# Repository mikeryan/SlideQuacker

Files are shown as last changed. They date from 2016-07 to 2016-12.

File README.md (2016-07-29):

# Wrong Island Con Slide Quacker

The Wrong Island Con Slide Quacker is an electronic conference badge
that's actually useful! You can pair it with your laptop and use it as a
traditional slide clicker, as it implements the HID over GATT profile.

The firmware is an app running on [Apache
Mynewt](http://mynewt.apache.org), an open source RTOS and BLE stack.
The app is heavily based on the bleprph example application.

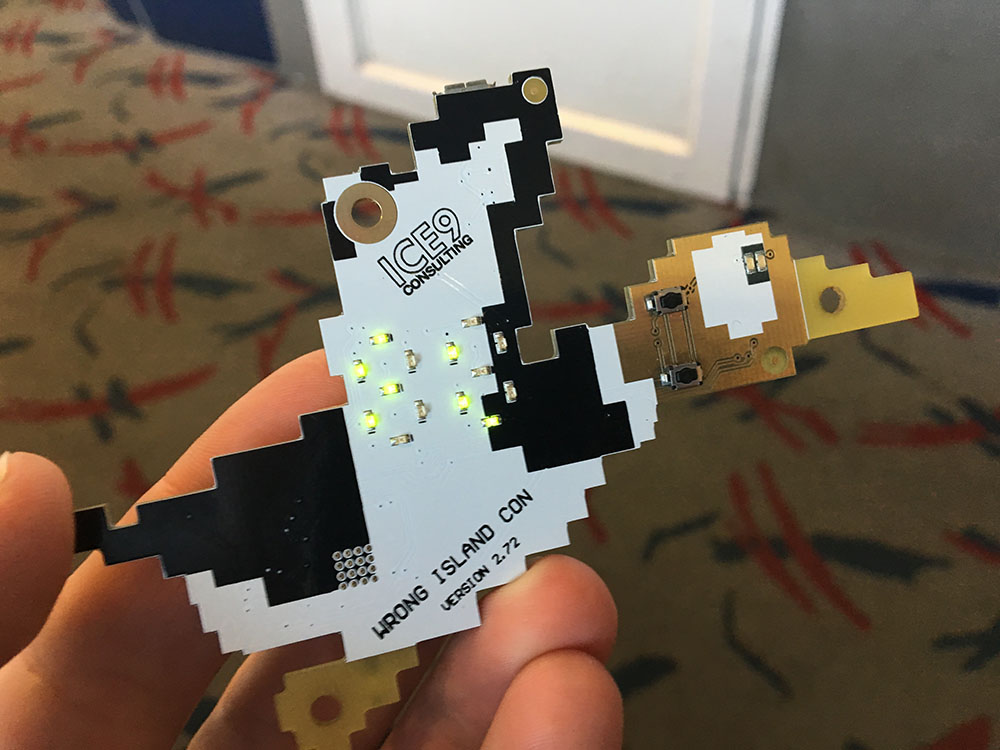
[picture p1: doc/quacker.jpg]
Slide Quacker


# Conference

This is the badge for Wrong Island Con 2.7, taking place on Catalina on
July 29th, 2016.

# Credits

- Conference: Richo Healey (http://psych0tik.net)
- Firmware: Mike Ryan of [ICE9 Consulting](http://ice9.us/)
- Hardware: nico (badge@n.routed.net)

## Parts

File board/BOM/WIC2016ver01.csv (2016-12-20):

Designator | Quantity | Description | Comment | Manufacturer | Manufacturer Part Number | Supplier 1 | Supplier Part Number 1 | Part Number
ANT1 | 1 | 2.4GHz antenna | 2.4GHz antenna | Johansen | 2450AT18A100E | Digi-Key | 712-1005-1-ND | 470-00204-00
B1 | 1 | HOLDER COIN CELL 2032 SMD | BATTERY_SOCKET_CR2032 | MPD (Memory Protection Devices) | BU2032SM-HD-G | Digi-Key | BU2032SM-HD-GDKR-ND
BAL1 | 1 |  | BAL-2450BM14E0003T
C1, C2 | 2 | CAP CER 0.1UF 100V 10% X7S 0603 | CAP_CER_0603_0.1UF_100V_10%_X7S | TDK Corporation | CGA3E3X7S2A104K080AB | Digi-Key | 445-6938-1-ND | 150-00222-00
C4, C5, C10, C11 | 4 | Capacitor, NP0, ±2% | 12pF |  |  |  |  | C0402-12p
C6, C7 | 2 | CAP CER 0.1UF 50V 10% X7R 0603 | CAP_CER_0603_0.1UF_50V_10%_X7R | TDK Corporation | CGA3E2X7R1H104K080AA | Digi-Key | 445-5666-1-ND | 150-00077-00
C8, C9 | 2 | CAP CER 2.2UF 6.3V 10% X7R 0603 | CAP_CER_0603_2.2UF_6.3V_10%_X7R | TDK Corporation | CGA3E1X7R0J225K080AC | Digi-Key | 445-6933-1-ND | 150-00101-00
C12 | 1 | CAP CER 1.5PF 100V C0G 0603 | CAP_CER_0603_1.5PF_100V_C0G | TDK Corporation | 251R14S1R0BV4T | Digi-Key | 251R14S1R0BV4T | 150-00508-00
C13 | 1 | CAP CER 0.047UF 25V 10% X7R 0603 | CAP_CER_0603_0.047UF_50V_10%_X7R | TDK Corporation | CGA3E2X7R1H473K080AA | Digi-Key | 445-5664-1-ND | 150-00147-00
C14 | 1 | CAP CER 2200PF 50V 5% NP0 0603 | CAP_CER_0603_2200PF_50V_5%_NP0 | TDK Corporation | CGA3E2C0G1H222J080AA | Digi-Key | 445-5656-1-ND | 150-00062-00
C15, C16 | 2 | CAP_CER_0603_4.7UF_6.3V_10%_X5R | CAP_CER_0603_4.7UF_6.3V_10%_X5R | TDK Corporation | CGA3E1X5R0J475K080AC | Digi-Key | 445-6934-1-ND | 150-00428-00
C17 | 1 | CAP CER 2.2UF 10V 10% X7S 0603 | CAP_CER_0603_2.2UF_10V_10%_X7S | TDK Corporation | CGA3E3X7S1A225K080AA | Digi-Key | 445-16108-1-ND | 140-00511-00
D1, D2 | 2 | LED CHIPLED BLUE 470NM 0603 SMD | LED_0603_BLUE_LB Q39G-L2N2-35-1 | OSRAM Opto Semiconductors Inc | LB Q39G-L2N2-35-1 | Digi-Key | 475-2816-1-ND | 370-00009-00
D3, D4, D5, D6, D7, D8, D9, D10, D11, D12, D13, D14, D15, D16, D18, D19 | 16 | LED GREEN CLEAR 0603 SMD | LED_0603_GREEN_LG_LTST-C190GKT | Lite-On Inc | LTST-C190GKT | Digi-Key | 160-1183-1-ND | 370-00010-00
D17 | 1 | DIODE SCHOTTKY 30V 0.2A SOD123 | SCHOTTKY_BAT42W | Diodes Inc | BAT42W-7-F | Digi-Key | BAT42W-FDICT-ND | 480-00148-00
D20 | 1 | IC ESD PROTECTION LO CAP SOT23-6 | TVS_BI_INTERFACE_USB | STMicroelectronics | USBLC6-2SC6 | Digi-Key | 497-5235-1-ND
J1 | 1 | CONN HEADER 10POS DUAL SHRD SMD | JTAG | FCI | 20021521-00010T1LF | Digi-Key | 609-4054-ND | 210-00165-00
J3 | 1 | CONN RCPT MICRO USB B R/A SMD | CONN_USB_TE_1981568-1 | TE Connectivity | 1981568-1 | Digi-Key | A97800CT-ND | 210-00266-00
L1, L2 | 2 |  | FB_HZ0603A222R-10 | Laird-Signal Integrity Products | HZ0603A222R-10 | Digi-Key | 712-1492-1-ND, 712-1490-1-ND | 452-00009-00
R1, R2, R3, R4, R5, R6, R7, R8, R9 | 9 | RES 2.2K OHM 1/10W 1% 0603 SMD | RES_0603_2.2K_OHM_1/10W_1% | Panasonic Electronic Components | ERJ-3EKF2201V | Digi-Key | P2.20KHCT-ND | 470-00097-00
R10, R11, R12, R13 | 4 | RES ARRAY 24 OHM 4 RES 1206 | RES_ARRAY_24_OHM_4_RES_1206_ACASA1003E1003P100_1 | Vishay Beyschlag | YC164-JR-07470RL | Digi-Key | YC164-JR-07470RL | 000-00000-00
R14, R15 | 2 | RES 1.07K OHM 1/10W 1% 0603 SMD | RES_0603_1.07K_OHM_1/10W_1% | Panasonic Electronic Components | ERJ-3EKF1071V | Digi-Key | P1.07KHCT-ND | 470-00114-00
R16 | 1 | RES 4.7K OHM 1/10W 1% 0603 SMD | RES_0603_4.7K_OHM_1/10W_1% | Panasonic Electronic Components | ERJ-3EKF4701V | Digi-Key | P4.70KHCT-ND | 470-00153-00
SW1, SW2 | 2 | SWITCH TACTILE SPST-NO 0.05A 12V | SWITCH_TL1015 | E-Switch | TL1015AF160QG | Digi-Key | EG4344CT-ND | 510-00025-00
SW3 | 1 | SMD slide Switch (ON-ON) | Switch | C&K Components | JS202011SCQN |  |  | JS202011SCQN
U1 | 1 | NXP MMA7660FC Acellerometer | MMA7660FC | NXP |  |  |  | MMA7660FC
U3 | 1 | Multi-protocol Bluetooth Low Energy, ANT and 2.4GHz proprietary system-on-chip | NRF51822-QFAC-R | Nordic Semiconductor | nRF51x22-QFAA |  |  | NRF51822-QFAC-R
U4 | 1 | CP2104 USB to Serial converter | CP2104 |  |  | Digi-Key | 336-2008-5-ND
X1 | 1 | XTAL SMD 2520, 16MHz, 8pF, ±15ppm | 16MHz | NDK | NX2520SA-16MHZ-STD-CSW-5 |  |  | NX2520SA-16MHZ-STD-CSW-5
X2 | 1 | EPSON TOYOCOM - FC-135 32.768KHZ ±20PPM,9.0PF - CRYSTAL, SM, WATCH | 32.768kHz | Epson Toyocom | FC-135 32.768KHZ ±20PPM,9.0PF |  |  | XTAL_FC-135 32.768k

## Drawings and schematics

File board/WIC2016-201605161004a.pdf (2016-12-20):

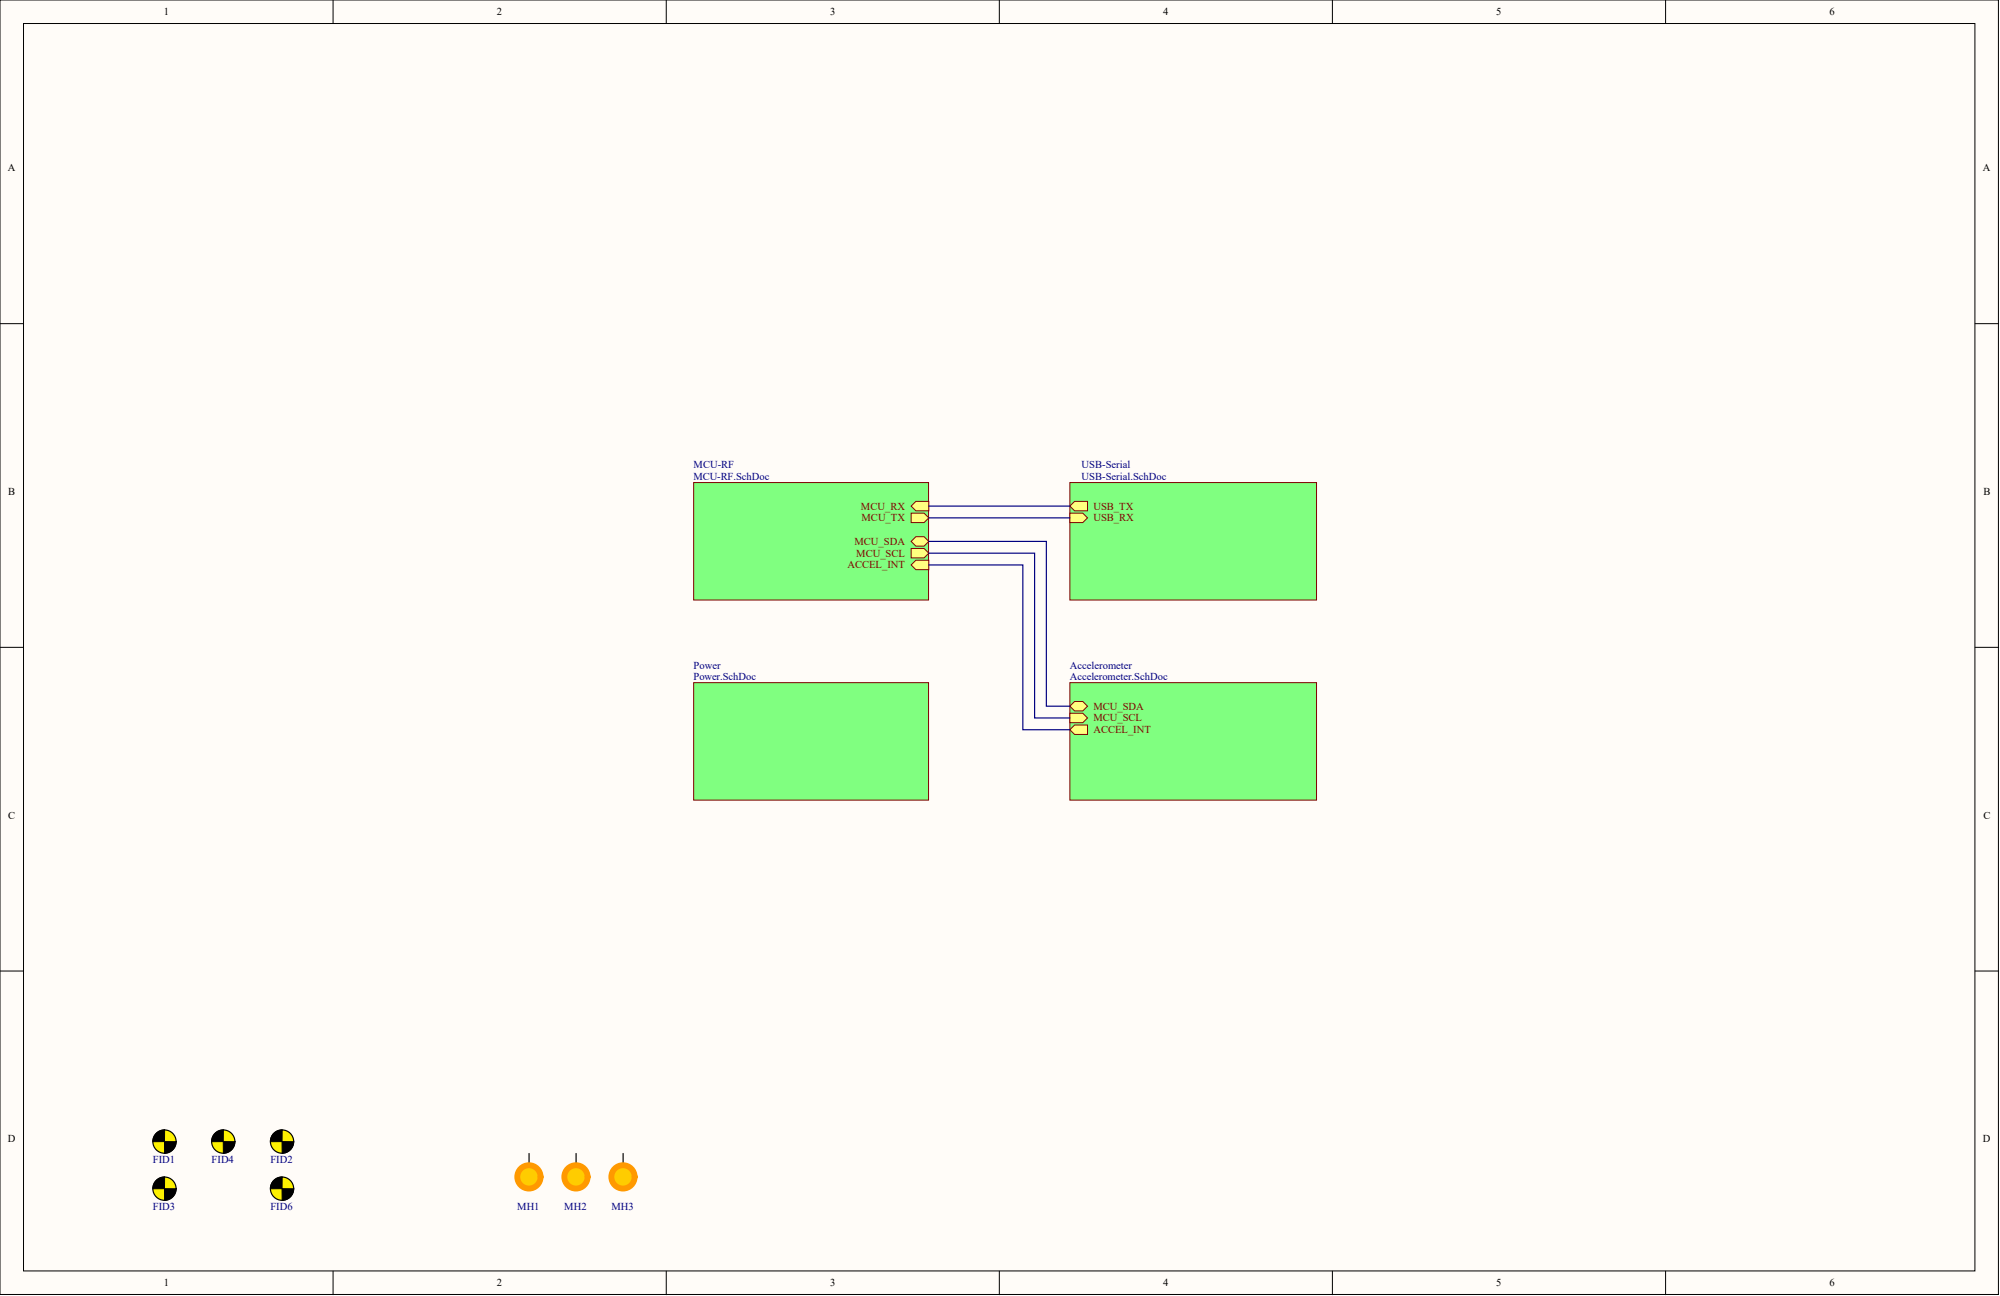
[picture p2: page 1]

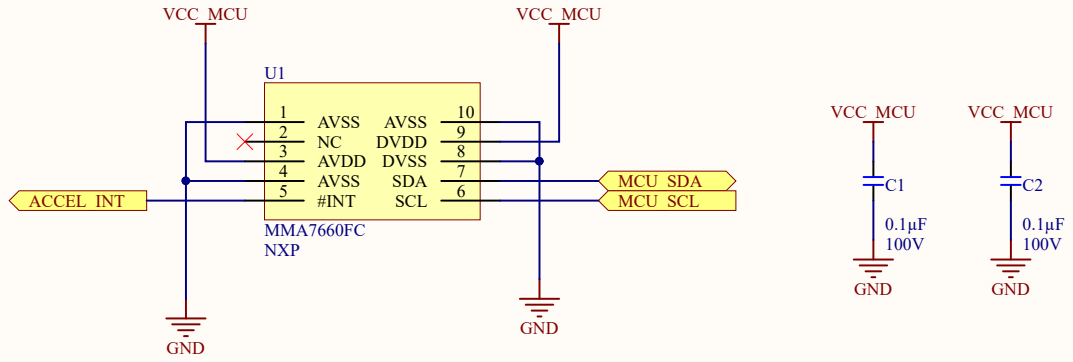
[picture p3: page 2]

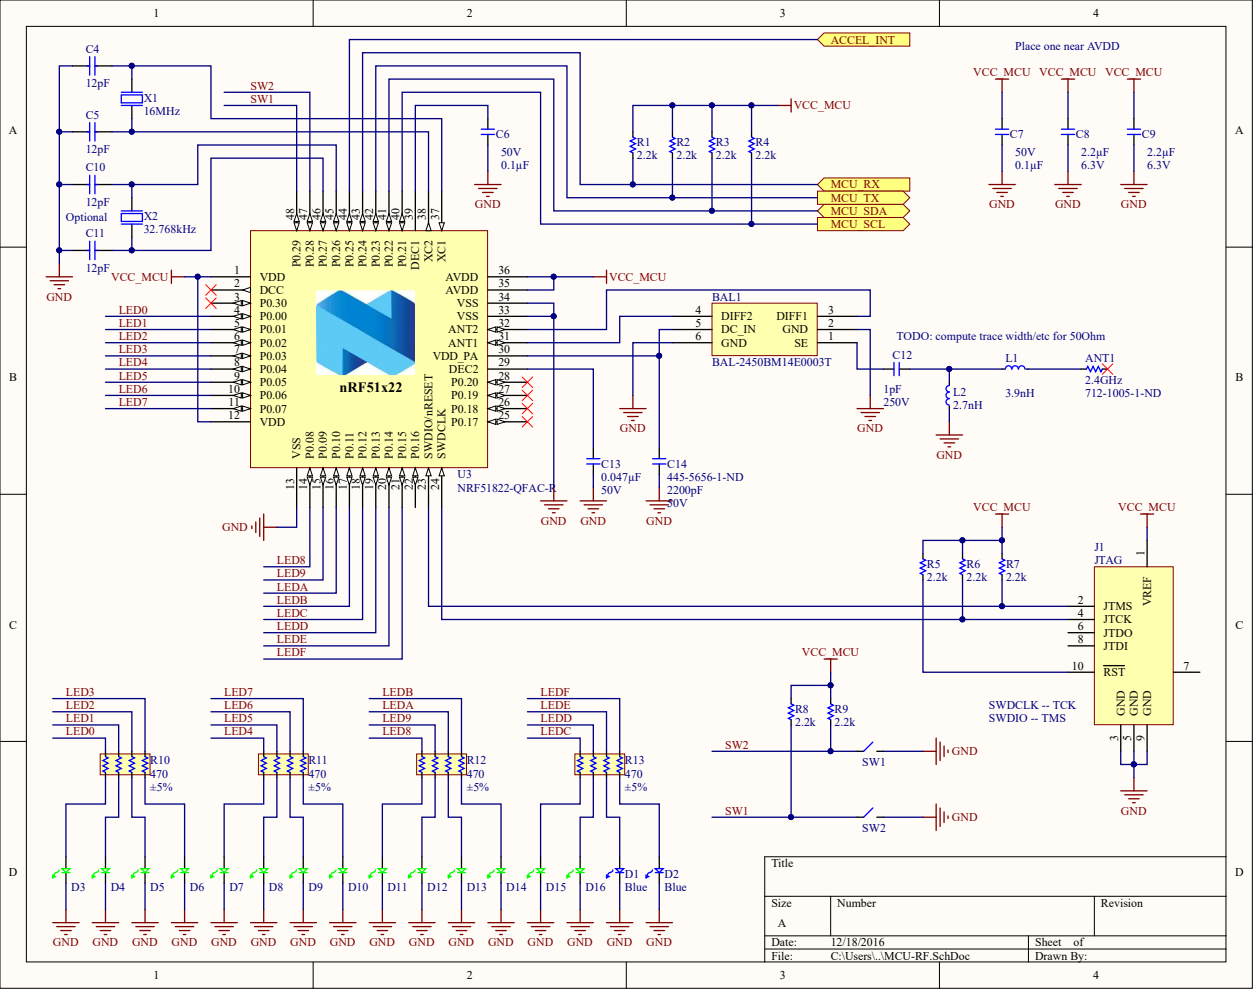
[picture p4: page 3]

Place one near AVDD

DCC 2
P0.30 3 | BAL1

TODO: compute trace width/etc for 50Ohm

GND

LEDC | | JTCK 4
LEDD | | JTDO 6

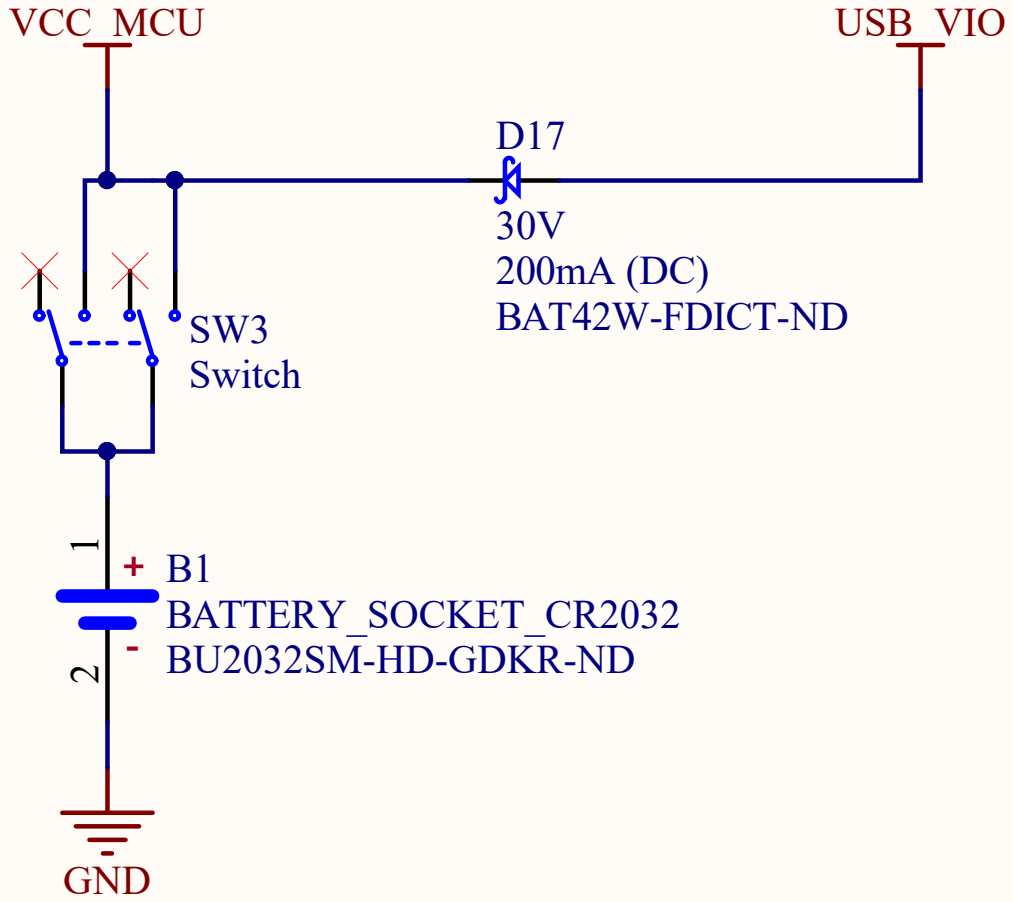
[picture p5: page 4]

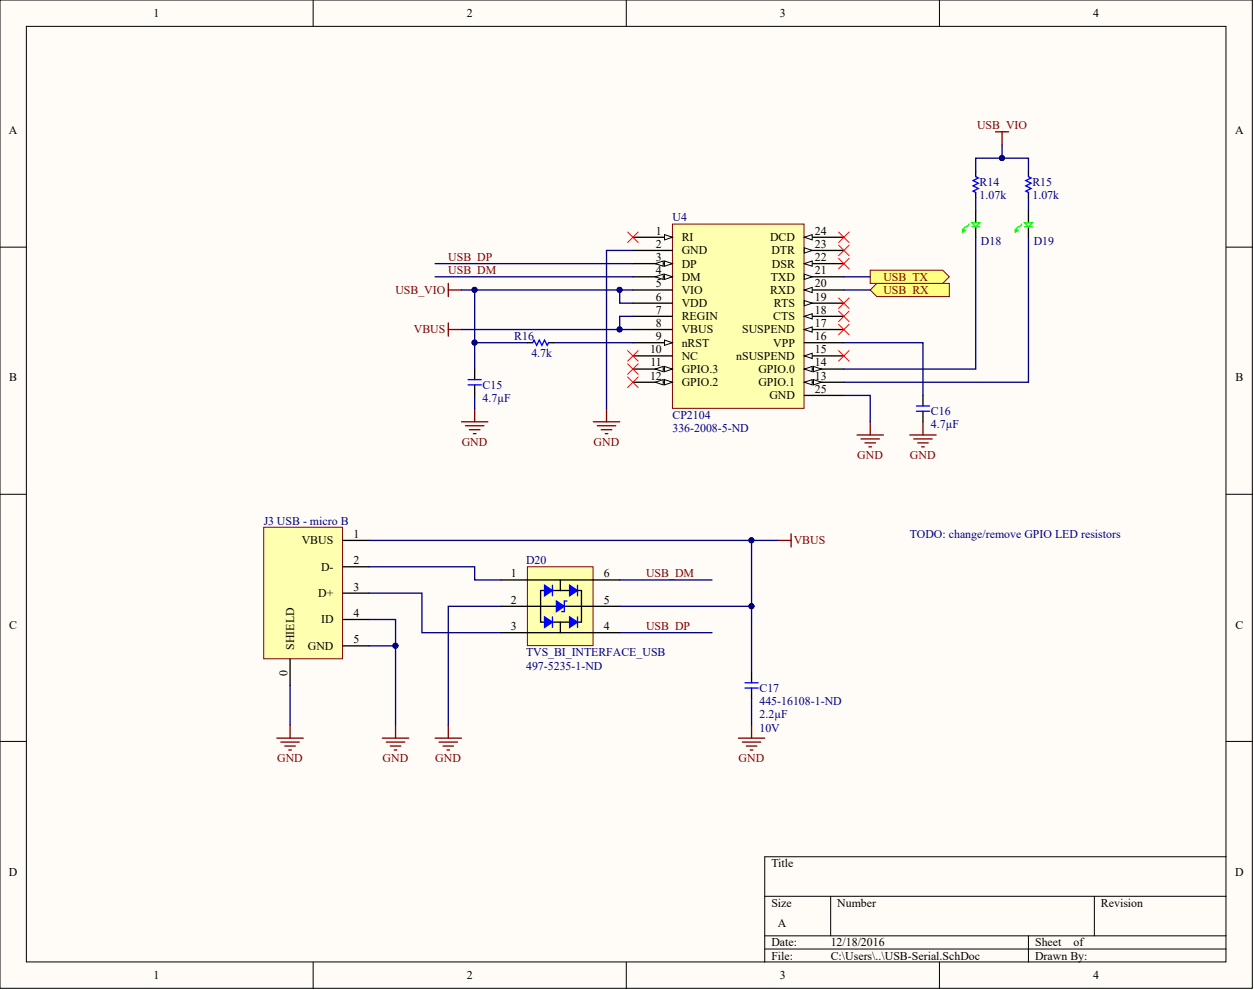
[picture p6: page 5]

GND 2 | USB_TX USB_RX

VDD 6

R16 | nRST 9

TODO: change/remove GPIO LED resistors

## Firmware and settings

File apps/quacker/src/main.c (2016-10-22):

/**
 * Copyright 2016 ICE9 Consulting
 *
 * Licensed to the Apache Software Foundation (ASF) under one
 * or more contributor license agreements.  See the NOTICE file
 * distributed with this work for additional information
 * regarding copyright ownership.  The ASF licenses this file
 * to you under the Apache License, Version 2.0 (the
 * "License"); you may not use this file except in compliance
 * with the License.  You may obtain a copy of the License at
 *
 *  http://www.apache.org/licenses/LICENSE-2.0
 *
 * Unless required by applicable law or agreed to in writing,
 * software distributed under the License is distributed on an
 * "AS IS" BASIS, WITHOUT WARRANTIES OR CONDITIONS OF ANY
 * KIND, either express or implied.  See the License for the
 * specific language governing permissions and limitations
 * under the License.
 */
#include <assert.h>
#include <string.h>
#include <stdio.h>
#include <errno.h>
#include "bsp/bsp.h"
#include "os/os.h"
#include "bsp/bsp.h"
#include "hal/hal_gpio.h"
#include "hal/hal_cputime.h"
#include "hal/hal_i2c.h"
#include "hal/hal_flash.h"
#include "hal/flash_map.h"
#include "console/console.h"
#include "fs/fs.h"
#include "fs/fsutil.h"
#include "nffs/nffs.h"

/* BLE */
#include "nimble/ble.h"
#include "host/host_hci.h"
#include "host/ble_hs.h"
#include "host/ble_hs_adv.h"
#include "host/ble_uuid.h"
#include "host/ble_att.h"
#include "host/ble_gap.h"
#include "host/ble_gatt.h"
#include "host/ble_l2cap.h"
#include "controller/ble_ll.h"

#include "quacker.h"

/** OUR ORIENTATION -- MOST IMPORTANT ASPECT OF THIS WHOLE THING */
enum orientation_t orientation;
#define ORIENTATION_FILE "/orientation.bin"

#define BSWAP16(x)  ((uint16_t)(((x) << 8) | (((x) & 0xff00) >> 8)))

/** Mbuf settings. */
#define MBUF_NUM_MBUFS      (12)
#define MBUF_BUF_SIZE       OS_ALIGN(BLE_MBUF_PAYLOAD_SIZE, 4)
#define MBUF_MEMBLOCK_SIZE  (MBUF_BUF_SIZE + BLE_MBUF_MEMBLOCK_OVERHEAD)
#define MBUF_MEMPOOL_SIZE   OS_MEMPOOL_SIZE(MBUF_NUM_MBUFS, MBUF_MEMBLOCK_SIZE)

static os_membuf_t quacker_mbuf_mpool_data[MBUF_MEMPOOL_SIZE];
struct os_mbuf_pool quacker_mbuf_pool;
struct os_mempool quacker_mbuf_mpool;

/** Log data. */
static struct log_handler quacker_log_console_handler;
struct log quacker_log;

/** Priority of the nimble host and controller tasks. */
#define BLE_LL_TASK_PRI             (OS_TASK_PRI_HIGHEST)

/** quacker task settings. */
#define QUACKER_TASK_PRIO           1
#define QUACKER_STACK_SIZE          (OS_STACK_ALIGN(336))

#define BUTTON_TASK_PRIO            2
#define BUTTON_STACK_SIZE           (OS_STACK_ALIGN(256))

#define LED_TASK_PRIO               3
#define LED_STACK_SIZE              (OS_STACK_ALIGN(128))

#define POWER_LED_TASK_PRIO         3
#define POWER_LED_STACK_SIZE        (OS_STACK_ALIGN(64))

#define ACCEL_TASK_PRIO             4
#define ACCEL_STACK_SIZE            (OS_STACK_ALIGN(128))

struct os_eventq quacker_evq;
struct os_task quacker_task;
bssnz_t os_stack_t quacker_stack[QUACKER_STACK_SIZE];

struct os_task button_task;
bssnz_t os_stack_t button_stack[BUTTON_STACK_SIZE];

struct os_eventq led_evq;
struct os_task led_task;
bssnz_t os_stack_t led_stack[LED_STACK_SIZE];

struct os_task power_led_task;
bssnz_t os_stack_t power_led_stack[POWER_LED_STACK_SIZE];

struct os_task accel_task;
bssnz_t os_stack_t accel_stack[ACCEL_STACK_SIZE];

/** Our global device address (public) */
uint8_t g_dev_addr[BLE_DEV_ADDR_LEN] = {0x0a, 0x0a, 0x0a, 0x0a, 0x0a, 0x0a};

/** Our random address (in case we need it) */
uint8_t g_random_addr[BLE_DEV_ADDR_LEN];

/** Device name - included in advertisements and exposed by GAP service. */
const char *quacker_device_name = "Slide Quacker";

/** Device properties - exposed by GAP service. */
const uint16_t quacker_appearance = 961; // BSWAP16(961); // HID keyboard
const uint8_t quacker_privacy_flag = 0;
uint8_t quacker_reconnect_addr[6];
uint8_t quacker_pref_conn_params[8];
uint8_t quacker_gatt_service_changed[4];

static int _nffs_init(void);
static int load_orientation(void);
static int save_orientation(void);

static int quacker_gap_event(int event, int status,
                             struct ble_gap_conn_ctxt *ctxt, void *arg);

/**
 * Utility function to log an array of bytes.
 */
static void
quacker_print_bytes(uint8_t *bytes, int len)
{
    int i;

    for (i = 0; i < len; i++) {
        QUACKER_LOG(INFO, "%s0x%02x", i != 0 ? ":" : "", bytes[i]);
    }
}

/**
 * Logs information about a connection to the console.
 */
static void
quacker_print_conn_desc(struct ble_gap_conn_desc *desc)
{
    QUACKER_LOG(INFO, "handle=%d peer_addr_type=%d peer_addr=",
                desc->conn_handle,
                desc->peer_addr_type);
    quacker_print_bytes(desc->peer_addr, 6);
    QUACKER_LOG(INFO, " conn_itvl=%d conn_latency=%d supervision_timeout=%d "
                      "encrypted=%d authenticated=%d",
                desc->conn_itvl,
                desc->conn_latency,
                desc->supervision_timeout,
                desc->sec_state.enc_enabled,
                desc->sec_state.authenticated);
}

/**
 * Enables advertising with the following parameters:
 *     o General discoverable mode.
 *     o Undirected connectable mode.
 */
static void
quacker_advertise(void)
{
    struct ble_hs_adv_fields fields;
    int rc;

    /**
     *  Set the advertisement data included in our advertisements:
     *     o Advertising tx power.
     *     o Device name.
     *     o 16-bit service UUIDs (alert notifications).
     *     o Appearance.
     */

    memset(&fields, 0, sizeof fields);

    // fields.tx_pwr_lvl_is_present = 1;

    fields.name = (uint8_t *)quacker_device_name;
    fields.name_len = strlen(quacker_device_name);
    fields.name_is_complete = 1;

    fields.uuids16 = (uint16_t[]){ GATT_SVR_SVC_HID_UUID };
    fields.num_uuids16 = 1;
    fields.uuids16_is_complete = 1;

    fields.appearance = 961;
    fields.appearance_is_present = 1;

    rc = ble_gap_adv_set_fields(&fields);
    if (rc != 0) {
        QUACKER_LOG(ERROR, "error setting advertisement data; rc=%d\n", rc);
        return;
    }

    /* Begin advertising. */
    rc = ble_gap_adv_start(BLE_GAP_DISC_MODE_GEN, BLE_GAP_CONN_MODE_UND,
                           NULL, 0, NULL, quacker_gap_event, NULL);
    if (rc != 0) {
        QUACKER_LOG(ERROR, "error enabling advertisement; rc=%d\n", rc);
        return;
    }
}

/**
 * The nimble host executes this callback when a GAP event occurs.  The
 * application associates a GAP event callback with each connection that forms.
 * quacker uses the same callback for all connections.
 *
 * @param event                 The type of event being signalled.
 * @param status                The error code associated with the event
 *                                  (0 = success).
 * @param ctxt                  Various information pertaining to the event.
 * @param arg                   Application-specified argument; unuesd by
 *                                  quacker.
 *
 * @return                      0 if the application successfully handled the
 *                                  event; nonzero on failure.  The semantics
 *                                  of the return code is specific to the
 *                                  particular GAP event being signalled.
 */
static int
quacker_gap_event(int event, int status, struct ble_gap_conn_ctxt *ctxt,
                  void *arg)
{
    int authenticated;
    int rc;

    switch (event) {
    case BLE_GAP_EVENT_CONN:
        /* A new connection has been established or an existing one has been
         * terminated.
         */
        QUACKER_LOG(INFO, "connection %s; status=%d ",
                    status == 0 ? "up" : "down", status);
        quacker_print_conn_desc(ctxt->desc);
        QUACKER_LOG(INFO, "\n");

        if (status != 0) {
            /* Connection terminated; resume advertising. */
            quacker_advertise();
        }
        return 0;

    case BLE_GAP_EVENT_CONN_UPDATED:
        /* The central has updated the connection parameters. */
        QUACKER_LOG(INFO, "connection updated; status=%d ", status);
        quacker_print_conn_desc(ctxt->desc);
        QUACKER_LOG(INFO, "\n");
        return 0;

    case BLE_GAP_EVENT_LTK_REQUEST:
        /* An encryption procedure (bonding) is being attempted.  The nimble
         * stack is asking us to look in our key database for a long-term key
         * corresponding to the specified ediv and random number.
         */
        QUACKER_LOG(INFO, "looking up ltk with ediv=0x%02x rand=0x%llx\n",
                    ctxt->ltk_params->ediv, ctxt->ltk_params->rand_num);

        /* Perform a key lookup and populate the context object with the
         * result.  The nimble stack will use this key if this function returns
         * success.
         */
        rc = keystore_lookup(ctxt->ltk_params->ediv,
                             ctxt->ltk_params->rand_num, ctxt->ltk_params->ltk,
                             &authenticated);
        if (rc == 0) {
            ctxt->ltk_params->authenticated = authenticated;
            QUACKER_LOG(INFO, "ltk=");
            quacker_print_bytes(ctxt->ltk_params->ltk,
                                sizeof ctxt->ltk_params->ltk);
            QUACKER_LOG(INFO, " authenticated=%d\n", authenticated);
        } else {
            QUACKER_LOG(INFO, "no matching ltk\n");
        }

        /* Indicate whether we were able to find an appropriate key. */
        return rc;

    case BLE_GAP_EVENT_KEY_EXCHANGE:
        /* The central is sending us key information or vice-versa.  If the
         * central is doing the sending, save the long-term key in the in-RAM
         * database.  This permits bonding to occur on subsequent connections
         * with this peer (as long as quacker isn't restarted!).
         */
        if (ctxt->key_params->is_ours   &&
            ctxt->key_params->ltk_valid &&
            ctxt->key_params->ediv_rand_valid) {

            rc = keystore_add(ctxt->key_params->ediv,
                              ctxt->key_params->rand_val,
                              ctxt->key_params->ltk,
                              ctxt->desc->sec_state.authenticated);
            if (rc != 0) {
                QUACKER_LOG(INFO, "error persisting LTK; status=%d\n", rc);
            }
        }
        return 0;

    case BLE_GAP_EVENT_SECURITY:
        /* Encryption has been enabled or disabled for this connection. */
        QUACKER_LOG(INFO, "security event; status=%d ", status);
        quacker_print_conn_desc(ctxt->desc);
        QUACKER_LOG(INFO, "\n");
        return 0;
    }

    return 0;
}

/**
 * Event loop for the main quacker task.
 */
static void
quacker_task_handler(void *unused)
{
    struct os_event *ev;
    struct os_callout_func *cf;
    int rc;

    rc = ble_hs_start();
    assert(rc == 0);

    /* Begin advertising. */
    quacker_advertise();

    while (1) {
        ev = os_eventq_get(&quacker_evq);
        switch (ev->ev_type) {
        case OS_EVENT_T_TIMER:
            cf = (struct os_callout_func *)ev;
            assert(cf->cf_func);
            cf->cf_func(CF_ARG(cf));
            break;
        default:
            assert(0);
            break;
        }
    }
}

// FIXME - find a better way to inject HID reports
extern uint8_t gatt_svr_hid_report[8];

static void
button_task_handler(void *unused)
{
    static const uint8_t report_char[] = { 0x50, 0x4F }; // left and right
    static const int button[] = { BUTTON1, BUTTON2 };
    int state[] = { 1, 1 };
    int count[] = { 0, 0 };
    int i;

#define CHECK_MSEC 5
#define PRESS_MSEC 20
#define RELEASE_MSEC 100

    hal_gpio_init_out(LED_EYE1, 0);

    hal_gpio_init_in(BUTTON1, GPIO_PULL_DOWN);
    hal_gpio_init_in(BUTTON2, GPIO_PULL_DOWN);

    while (1) {
        for (i = 0; i < 2; ++i) {
            int val = hal_gpio_read(button[i]);
            if (state[i] == 0 && val > 0) {
                ++count[i];
                if (count[i] > PRESS_MSEC / CHECK_MSEC) {
                    gatt_svr_hid_report[2] = 0x00;
                    ble_gatts_chr_updated(0x21);
                    hal_gpio_clear(LED_EYE1);
                    state[i] = 1;
                    count[i] = 0;
                }
            } else if (state[i] == 1 && val == 0) {
                ++count[i];
                if (count[i] > RELEASE_MSEC / CHECK_MSEC) {
                    gatt_svr_hid_report[2] = report_char[i];
                    ble_gatts_chr_updated(0x21);
                    hal_gpio_set(LED_EYE1);
                    state[i] = 0;
                    count[i] = 0;
                }
            }
        }
        os_time_delay(OS_TICKS_PER_SEC / 200);
    }
}

static void
led_task_handler(void *unused)
{
    enum orientation_t prev_orientation = orientation;
    while (1) {
        switch (orientation) {
        case FLAT:
            led_scroll("FLAT");
            led_static("FL");
            os_time_delay(5000);
            break;
        case UPRIGHT:
            led_scroll("UPRIGHT");
            led_static("UP");
            os_time_delay(5000);
            break;
        case RUBBER:
            led_scroll("rubber");
            led_static("ru");
            os_time_delay(5000);
            if ((rand() % 5) == 0)
                led_scroll("dspill_is_odious");
            break;
        case NONE:
        default:
            led_spinner();
            break;
        }

        if (orientation != prev_orientation) {
            save_orientation();
            prev_orientation = orientation;
        }
    }
}

static void
power_led_task_handler(void *unused)
{
    hal_gpio_init_out(LED_EYE1, 0);
    while (1) {
        hal_gpio_set(LED_EYE2);
        os_time_delay(OS_TICKS_PER_SEC / 30);
        hal_gpio_clear(LED_EYE2);
        os_time_delay(3 * OS_TICKS_PER_SEC);
    }
}

static void
accel_task_handler(void *unused)
{
    // hal_i2c_init(0);
    while (1) {
        os_time_delay(OS_TICKS_PER_SEC);
    }
}

/**
 * main
 *
 * The main function for the project. This function initializes the os, calls
 * init_tasks to initialize tasks (and possibly other objects), then starts the
 * OS. We should not return from os start.
 *
 * @return int NOTE: this function should never return!
 */
int
main(void)
{
    struct ble_hs_cfg cfg;
    uint32_t seed;
    int rc;
    int i;

    g_dev_addr[0] = NRF_FICR->DEVICEADDRTYPE;
    memcpy(g_dev_addr, (void *)NRF_FICR->DEVICEADDR + 2, 6);

    /* Initialize OS */
    os_init();

    /* Set cputime to count at 1 usec increments */
    rc = cputime_init(1000000);
    assert(rc == 0);

    /* Seed random number generator with least significant bytes of device
     * address.
     */
    seed = 0;
    for (i = 0; i < 4; ++i) {
        seed |= g_dev_addr[i];
        seed <<= 8;
    }
    srand(seed);

    /* Initialize msys mbufs. */
    rc = os_mempool_init(&quacker_mbuf_mpool, MBUF_NUM_MBUFS,
                         MBUF_MEMBLOCK_SIZE, quacker_mbuf_mpool_data,
                         "quacker_mbuf_data");
    assert(rc == 0);

    rc = os_mbuf_pool_init(&quacker_mbuf_pool, &quacker_mbuf_mpool,
                           MBUF_MEMBLOCK_SIZE, MBUF_NUM_MBUFS);
    assert(rc == 0);

    rc = os_msys_register(&quacker_mbuf_pool);
    assert(rc == 0);

    /* NFFS */
    _nffs_init();

    /* LEDs */
    led_init();

    /* Initialize the logging system. */
    log_init();
    log_console_handler_init(&quacker_log_console_handler);
    log_register("quacker", &quacker_log, &quacker_log_console_handler);

    os_task_init(&quacker_task, "quacker", quacker_task_handler,
                 NULL, QUACKER_TASK_PRIO, OS_WAIT_FOREVER,
                 quacker_stack, QUACKER_STACK_SIZE);

    os_task_init(&button_task, "button", button_task_handler,
                 NULL, BUTTON_TASK_PRIO, OS_WAIT_FOREVER,
                 button_stack, BUTTON_STACK_SIZE);

    os_task_init(&led_task, "led", led_task_handler,
                 NULL, LED_TASK_PRIO, OS_WAIT_FOREVER,
                 led_stack, LED_STACK_SIZE);

    os_task_init(&power_led_task, "power_led", power_led_task_handler,
                 NULL, POWER_LED_TASK_PRIO, OS_WAIT_FOREVER,
                 power_led_stack, POWER_LED_STACK_SIZE);

    os_task_init(&accel_task, "accel", accel_task_handler,
                 NULL, ACCEL_TASK_PRIO, OS_WAIT_FOREVER,
                 accel_stack, ACCEL_STACK_SIZE);

    /* Initialize the keystore */
    rc = keystore_init();
    assert(rc == 0);

    /* Initialize the BLE LL */
    rc = ble_ll_init(BLE_LL_TASK_PRI, MBUF_NUM_MBUFS, BLE_MBUF_PAYLOAD_SIZE);
    assert(rc == 0);

    /* Initialize the BLE host. */
    cfg = ble_hs_cfg_dflt;
    cfg.max_hci_bufs = 3;
    cfg.max_connections = 1;
    cfg.max_attrs = 50;
    cfg.max_services = 6;
    cfg.max_client_configs = 10;
    cfg.max_gattc_procs = 2;
    cfg.max_l2cap_chans = 3;
    cfg.max_l2cap_sig_procs = 1;
    cfg.sm_bonding = 1;
    cfg.sm_our_key_dist = BLE_L2CAP_SM_PAIR_KEY_DIST_ENC;
    cfg.sm_their_key_dist = BLE_L2CAP_SM_PAIR_KEY_DIST_ENC;

    /* Initialize eventq */
    os_eventq_init(&quacker_evq);

    rc = ble_hs_init(&quacker_evq, &cfg);
    assert(rc == 0);

    /* Initialize LED eventq */
    os_eventq_init(&led_evq);

    /* Initialize the console (for log output). */
    rc = console_init(NULL);
    assert(rc == 0);

    /* orientation */
    load_orientation();


    /* Register GATT attributes (services, characteristics, and
     * descriptors).
     */
    gatt_svr_init();

    /* Start the OS */
    os_start();

    /* os start should never return. If it does, this should be an error */
    assert(0);

    return 0;
}

static int
_nffs_init(void)
{
    struct nffs_area_desc descs[NFFS_AREA_MAX];
    int rc;
    int cnt;

    rc = hal_flash_init();
    assert(rc == 0);

    rc = nffs_init();
    assert(rc == 0);

    cnt = NFFS_AREA_MAX;
    rc = flash_area_to_nffs_desc(FLASH_AREA_NFFS, &cnt, descs);
    assert(rc == 0);
    if (nffs_detect(descs) == FS_ECORRUPT) {
        rc = nffs_format(descs);
        assert(rc == 0);
    }

    return rc;
}

static int
load_orientation(void)
{
    int rc;
    char *str;

    rc = fsutil_read_file(ORIENTATION_FILE, 0, sizeof(orientation), &orientation, NULL);
    if (rc != 0) {
        // create a new file if necessary
        rc = save_orientation();
    }

    switch (orientation) {
    case FLAT:
        str = "flat";
        break;
    case UPRIGHT:
        str = "upright";
        break;
    case RUBBER:
        str = "rubber";
        break;
    case NONE:
    default:
        str = "none";
    }
    strcpy(quacker_orientation, str);

    return rc;
}

static int
save_orientation(void)
{
    int rc;

    // save keys
    rc = fsutil_write_file(ORIENTATION_FILE, &orientation, sizeof(orientation));
    return rc;
}

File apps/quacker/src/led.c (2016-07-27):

/**
 * Copyright 2016 ICE9 Consulting
 *
 * Licensed under the Apache License, Version 2.0 (the "License");
 * you may not use this file except in compliance with the License.
 * You may obtain a copy of the License at
 *
 *     http://www.apache.org/licenses/LICENSE-2.0
 *
 *     Unless required by applicable law or agreed to in writing, software
 *     distributed under the License is distributed on an "AS IS" BASIS,
 *     WITHOUT WARRANTIES OR CONDITIONS OF ANY KIND, either express or implied.
 *     See the License for the specific language governing permissions and
 *     limitations under the License.
 */

#include <ctype.h>
#include <stdint.h>

#include "os/os.h"
#include "hal/hal_gpio.h"

// speedhack
#include "mcu/nrf51.h"

/* 7segs look like this:
 *     _       0
 *    |_|    1 6 5
 *    |_|    2 3 4
 */

static const uint8_t digits[] = {
    0b0111111, /* 0 */ 0b0110000, /* 1 */ 0b1101101, /* 2 */ 0b1111001, /* 3 */
    0b1110010, /* 4 */ 0b1011011, /* 5 */ 0b1011111, /* 6 */ 0b0110011, /* 7 */
    0b1111111, /* 8 */ 0b1111011, /* 9 */ 0b1110111, /* A */ 0b1011110, /* B */
    0b0001111, /* C */ 0b1111100, /* D */ 0b1001111, /* E */ 0b1000111, /* F */
};

static const uint8_t alpha[] = {
    0b1110111, // A
    0b1011110, // B
    0b1001100, // C, lower
    0b1111100, // D
    0b1001111, // E
    0b1000111, // F
    0b1111011, // G, same as 9
    0b1010110, // H, lower
    0b0110000, // I
    0b0111000, // J
    0b0000000, // K [no repr]
    0b0001110, // L
    0b0000000, // M [no repr]
    0b1010100, // N
    0b1011100, // O, lower
    0b1100111, // P
    0b1110011, // Q
    0b1000100, // R
    0b1011011, // S, same as 5
    0b1001110, // T
    0b0011100, // U, lower
    0b0011100, // V, lower, same as u
    0b0000000, // W [no repr]
    0b1110110, // X
    0b1111010, // Y
    0b0000000, // Z [no repr]
}; 

struct capital {
    char letter;
    uint8_t repr;
};

static const struct capital capitals[] = {
    { 'C', 0b0001111, },
    { 'O', 0b0111111, },
    { 'U', 0b0111110, },
    { 'V', 0b0111110, },
};

static
uint8_t char_repr(char input)
{
    if (input == '*') // ö
        return 0b1011101;

    if (isalpha(input)) {
        if (isupper(input)) {
            int i;
            for (i = 0; i < sizeof(capitals)/sizeof(struct capital); ++i)
                if (input == capitals[i].letter)
                    return capitals[i].repr;
            // didn't find it, no capital representations
            input = tolower(input);
        }
        return alpha[input - 'a'];
    }

    if (isdigit(input))
        return digits[input - '0'];

    return 0b0000000;
}

static void
led_putchar(char input, int left)
{
    uint16_t repr = char_repr(input);

    if (left) {
        NRF_GPIO->OUTCLR = ~repr & 0x7f;
        NRF_GPIO->OUTSET = repr;
    } else {
        repr <<= 7;
        NRF_GPIO->OUTCLR = ~repr & (0x7f << 7);
        NRF_GPIO->OUTSET = repr;
    }
}

void
led_scroll(char *message)
{
    uint16_t display = 0;
    char *next;

#define SHOW NRF_GPIO->OUTCLR = ~display & 0x3fff; NRF_GPIO->OUTSET = display; os_time_delay(500)

    SHOW;
    for (next = message; *next; ++next) {
        display >>= 7;
        display |= char_repr(*next) << 7;
        SHOW;
    }
    display >>= 7;
    SHOW;
    display >>= 7;
    SHOW;
}

void
led_static(char *letters)
{
    led_putchar(letters[0], 1);
    led_putchar(letters[1], 0);
}

void
led_number(uint8_t num)
{
    // TODO
}

void
led_number_hex(uint8_t num)
{
    // TODO
}

void
led_spinner(void)
{
    const int led_order[] = { 7, 0, 1, 2, 3, 10, 11, 12 };
    int state = 0;
    int next;

    led_static("  "); // clear

    do {
        next = (state + 1) % (sizeof(led_order) / sizeof(int));
        hal_gpio_clear(led_order[state]);
        hal_gpio_set(led_order[next]);
        os_time_delay(100);
        state = next;
    } while (state > 0);
}

void
led_spinner_pairing(void)
{
    int i;

    led_static("  "); // clear

    while (1) {
        for (i = 0; i < 14; ++i) {
            // skip center
            if (i == 6 || i == 13)
                continue;
            hal_gpio_toggle(i);
            os_time_delay(30);
        }
    }
}


void
led_init(void)
{
    int i;
    for (i = 0; i < 16; ++i)
        hal_gpio_init_out(i, 0);
}

// run through the alphabet
void
test_alpha(void)
{
    int i = 0;
    while (1) {
        led_putchar('A' + i, 1);
        led_putchar('a' + i, 0);
        os_time_delay(500);

        i = (i + 1) % 26;
    }
}

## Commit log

2016-07-28 save orientation to NFFS
    Note that this crashes, but saving does work.
    [main.c]
2016-10-22 debounce button presses
2016-12-20 board: add gerbers for board
    [WIC2016ver01.csv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]
